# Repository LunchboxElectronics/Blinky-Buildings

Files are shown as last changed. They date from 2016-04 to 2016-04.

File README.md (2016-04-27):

# Blinky-Buildings
Blinky Buildings v1
- About:  
Blinky Buildings is a simple kit to teach people how to make derivatives of open source hardware. You are welcome to create a derivative of this kit as long as it abides by the open source hardware definition. 

This kit blinks 20 LEDs from an ATtiny85. The code was written in Arduino and uses a technique called Charlieplexing to drive multiple LEDs using just 5 pins of the ATtiny.

This kit assumes you know how to solder. If not, there are plenty of online tutorials on how to solder. The kit is fairly quick to put together, roughly 10 minutes, and the chip has been programmed for you! 

- Materials and tools:
Here are the parts you’ll need to get stared:
20 LEDs (with a max current of 20mA)
5 Resistors (for 3.2v forward voltage LEDs, I used 680 Ohm resistors)
1 ATtiny85
1 battery holder
1 3v battery
1 switch

Here are the tools you’ll need to get stared:
Soldering Iron
Solder
wire clippers

More information and documentation, including an assembly guide, lives here: bit.ly/blinkybuildings

- Attribution: 
The code for this project was downloaded from http://code.google.com/p/avr-hardware-random-number-generation/ Original code by Geoff  Steele, altered by commenting some code out to blink LEDs on and off by Alicia Gibb.
The original Fritzing design of charlieplexing 20 LEDs was downloaded from http://fritzing.org/projects/charlieplex-snowfallshooting-star-20-leds by Davy Uittenbogerd. Alicia Gibb drew this schematic in Eagle and altered in into the Empire State Blinky Building form factor.
The original code and the hardware files are both under a CC-BY-SA creative commons license.
Code: CC-BY-SA: Geoff Steele
Fritzing layout: CC-BY-SA: Davy Uittenbogerd
Blinky Building schematic, board file and BOM: CC-BY-SA: Alicia Gibb

- Licensing: 
Blinky Buildings is an open source hardware product and follows the open source hardware definition: www.oshwa.org/definition
The license on the source files for Blinky Buildings is CC-BY-SA

Distributed as-is; no warranty given. Not suitable for people who might eat electronics.

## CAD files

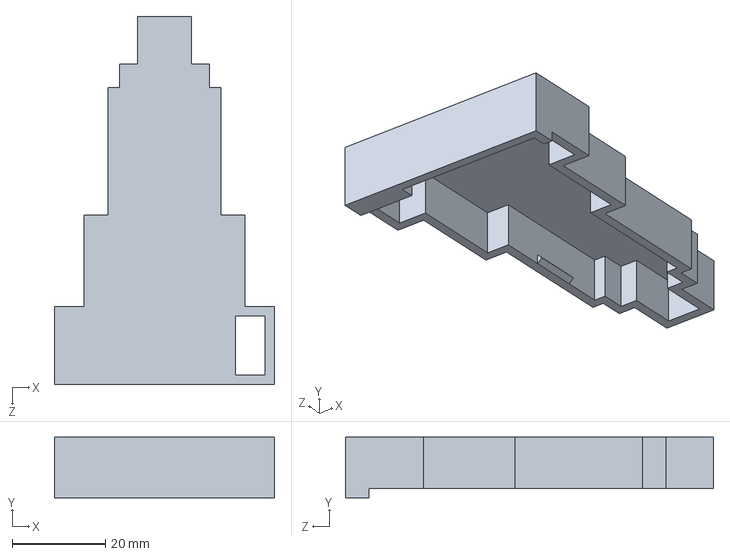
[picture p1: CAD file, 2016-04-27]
FinalBlinkyBuildingsCase.SLDPRT
47.2 x 13.0 x 78.9 mm

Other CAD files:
FinalBlinkyBuildingsCase.STL

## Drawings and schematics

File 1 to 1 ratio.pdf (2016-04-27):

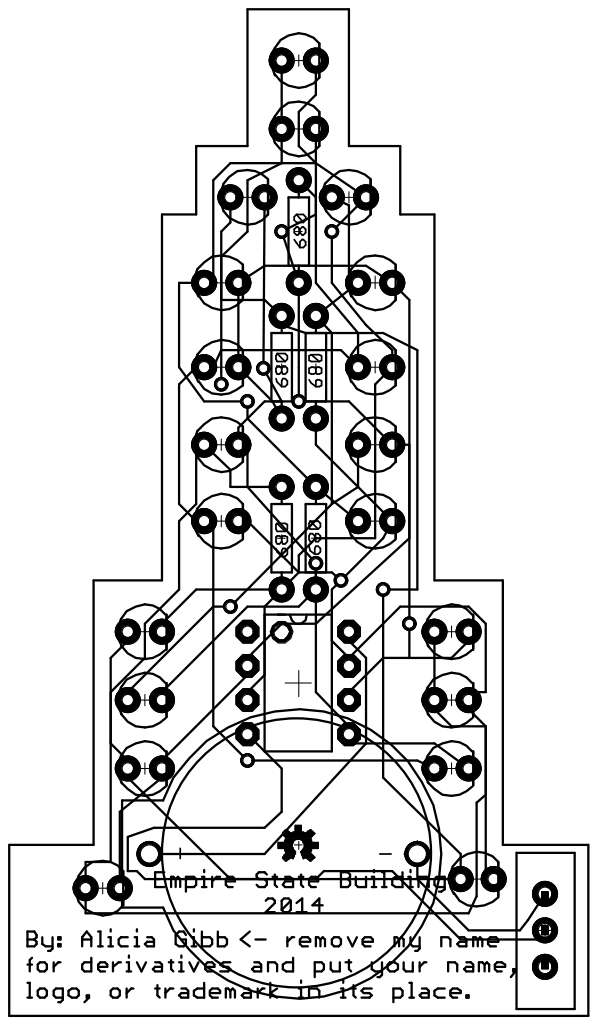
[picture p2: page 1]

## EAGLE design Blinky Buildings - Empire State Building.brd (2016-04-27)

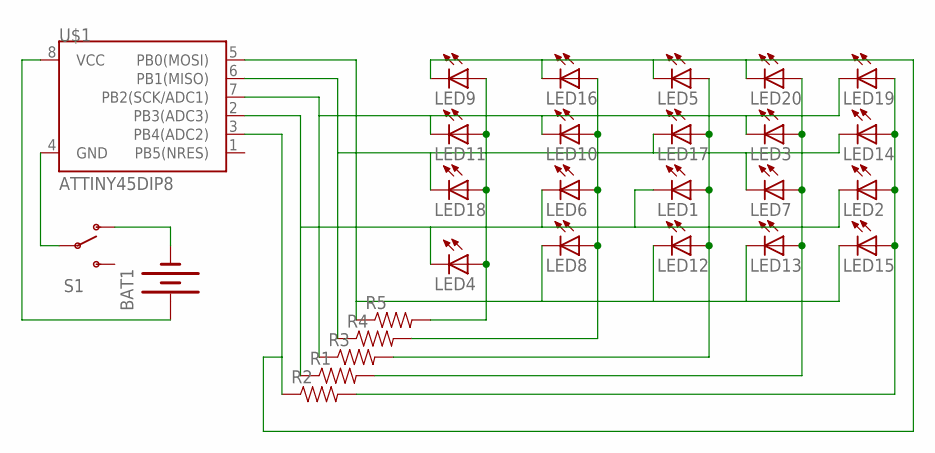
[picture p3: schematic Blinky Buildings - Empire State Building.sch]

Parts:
BAT1: BATTERY20PTH; BATTCOM_20MM_PTH
LED1, LED2, LED3, LED4, LED5, LED6, LED7, LED8, LED9, LED10, LED11, LED12, LED13, LED14, LED15, LED16, LED17, LED18, LED19, LED20: LED3MM
R1, R2, R3, R4, R5: RESISTORAXIAL-0.3; AXIAL-0.3
S1: SWITCH-SPSTKIT; SWITCH-SPDT_KIT
U$1: ATTINY45DIP8; DIP08

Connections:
unnamed: LED5.K (C), LED9.K (C), LED16.K (C), LED20.K (C), R2.P$1 (1), U$1.3 (PB4(ADC2))
unnamed: LED1.K (C), LED2.K (C), LED4.K (C), LED6.K (C), R1.P$1 (1), U$1.2 (PB3(ADC3))
unnamed: LED3.K (C), LED10.K (C), LED11.K (C), LED19.K (C), R3.P$1 (1), U$1.7 (PB2(SCK/ADC1))
unnamed: LED7.K (C), LED14.K (C), LED17.K (C), LED18.K (C), R4.P$1 (1), U$1.6 (PB1(MISO))
unnamed: LED8.K (C), LED12.K (C), LED13.K (C), LED15.K (C), R5.P$1 (1), U$1.5 (PB0(MOSI))
unnamed: LED3.A, LED7.A, LED13.A, LED20.A, R1.P$2 (2)
unnamed: LED4.A, LED9.A, LED11.A, LED18.A, R5.P$2 (2)
unnamed: LED6.A, LED8.A, LED10.A, LED16.A, R4.P$2 (2)
unnamed: LED1.A, LED5.A, LED12.A, LED17.A, R3.P$2 (2)
unnamed: LED2.A, LED14.A, LED15.A, LED19.A, R2.P$2 (2)
unnamed: S1.2, U$1.4 (GND)
unnamed: BAT1.1 (+), U$1.8 (VCC)
unnamed: BAT1.2 (-), S1.1 (O)

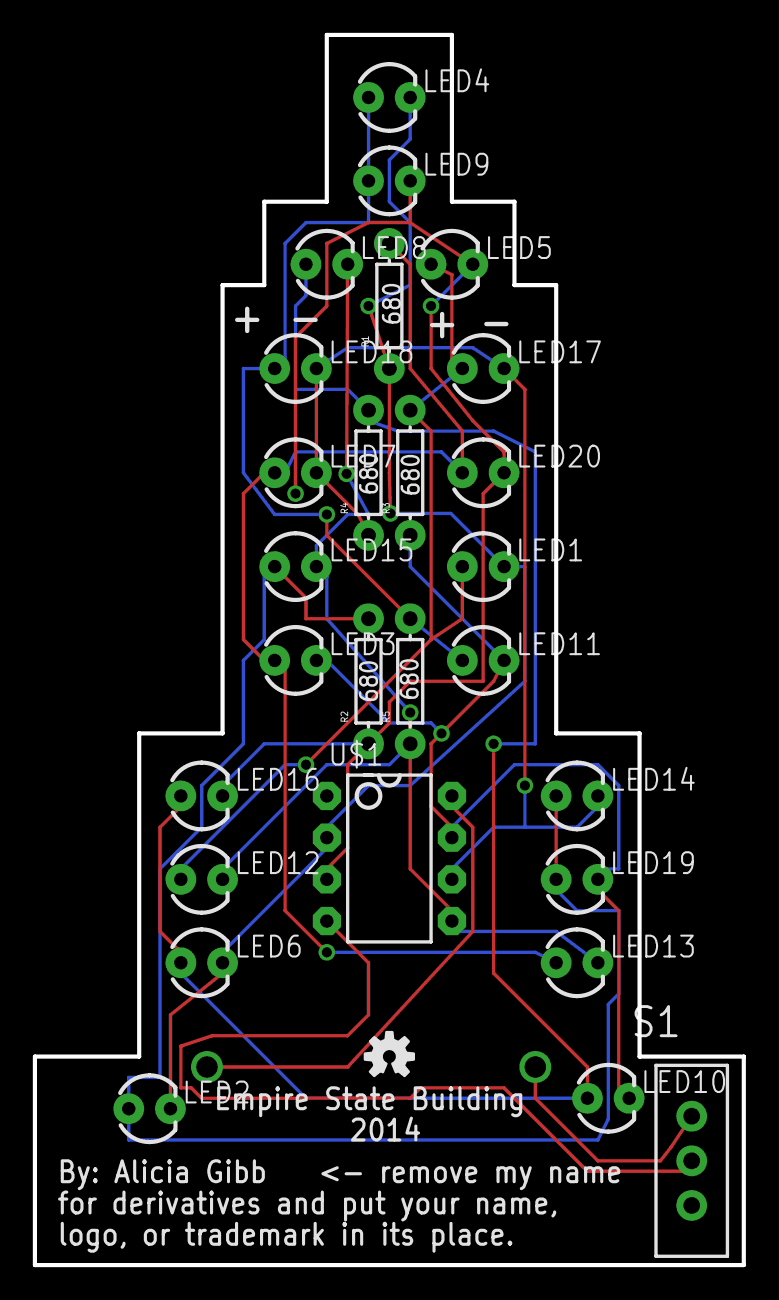
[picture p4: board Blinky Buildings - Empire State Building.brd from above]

Board: 2 copper layers, 43.2 x 74.9 mm, 29 parts (1 on the bottom side), 13 nets.

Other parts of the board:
U$2: OSHW-LOGO-S

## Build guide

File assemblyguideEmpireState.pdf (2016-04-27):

## Blinking Buildings Empire State Assembly Guide

Blinky Buildings kit contains:
20 LEDs
5 680 Ohm Resistors
1 ATtiny85

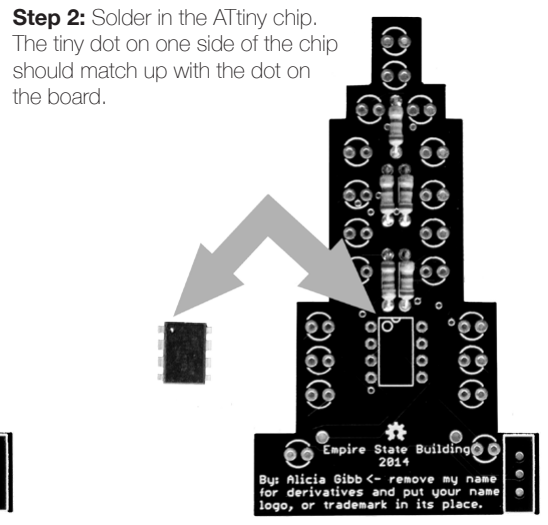
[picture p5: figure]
Step 2: Solder in the ATtiny chip. The tiny dot on one side of the chip should match up with the dot on the board.

## Assembly:

Tools you will need:
Soldering Iron
Solder
Wire clippers

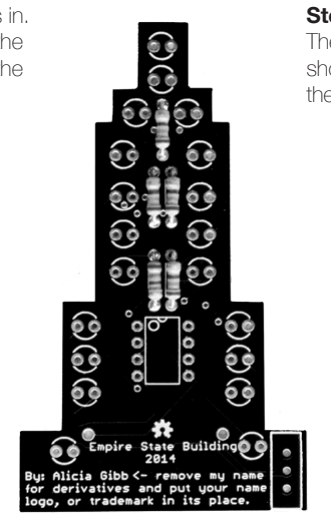
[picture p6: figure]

Step 1: Solder the 5 resistors in. Direction doesn't matter with the resistors. After soldering, cut the OHDGVR

1 Battery Holder
1 3v Battery
1 Switch

## LBE

Lunchbox Electronics

Step 5: On the back side of the board, solder in the battery holder. Insert the battery with the + face up.

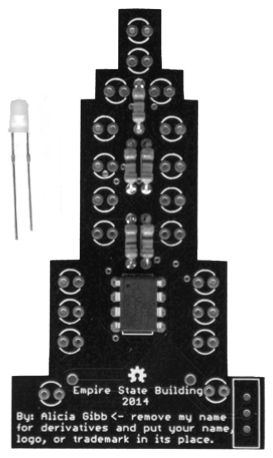
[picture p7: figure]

Step 6: <RX

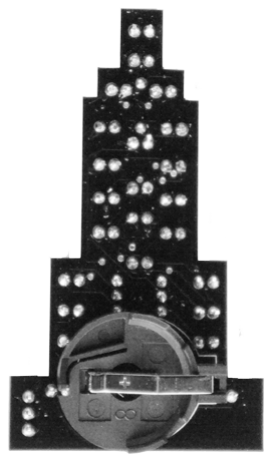
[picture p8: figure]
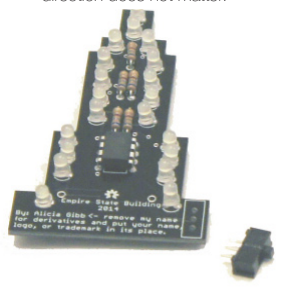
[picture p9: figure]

UH'RQH3RSWKHEDWWHU\LQDQGLSWKHVZLWFKRQ<D\%OLQNLQHVV

Step 4: Solder in the switch, direction does not matter.
Step 3: Take note of the direction of the LEDs. The long lead of the LED goes on the left side if your board is face up. &XWWKHOHDGRRQFHVROGHUHG6ROGHUDOO 20 LEDs in this direction.

Alicia Gibb
6RXUFHOHVELWO\EOLQN\EXLOGLQJV

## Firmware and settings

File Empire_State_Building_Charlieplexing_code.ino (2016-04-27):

#include <Entropy.h>
/* Original code downloaded fromhttps://github.com/strykeroz/ATTiny85-20-LED-snowflakes
Original code by Geoff  Steele. Alicia Gibb altered the code by commenting out the fade functions so the building blinks 
LEDs on and off rather than fade LEDs on and off. 
The original code is still all there if others wanted to keep playing with it, just put the duty cycle back in, 
which have a fade effect rather than a blink effect.
The delays have also been changed, but can easily be reinstated by looking at the original code.

____ _ _ _ _ ____ ___
/ ___| |__ __ _ _ __| (_) ___ _ __ | | _____ _|___ \ / _ \ ___ _ __ _____ __
| | | '_ \ / _` | '__| | |/ _ \ '_ \| |/ _ \ \/ / __) | | | / __| '_ \ / _ \ \ /\ / /
| |___| | | | (_| | | | | | __/ |_) | | __/> < / __/| |_| \__ \ | | | (_) \ V V /
\____|_| |_|\__,_|_| |_|_|\___| .__/|_|\___/_/\_\_____|\___/|___/_| |_|\___/ \_/\_/
|_|
Charlieplexing 20 LEDs using 5 ATTiny85 pins with fading by
varying the duty cycle of each LED in the 'tail'.
ATTiny85 connections
Leg Function
1 Reset, no connection
2 D3 GREEN
3 D4 ORANGE
4 GND
5 D0 WHITE
6 D1 BLUE
7 D2 YELLOW
8 +5V
Tested on ATTiny85 running at 8MHz.
*/


//// each block of 4 LEDs in the array is groupled by a common anode (+, long leg)
//// for simplicity of wiring on breadboard, using a colour code
#define GREEN 0
#define ORANGE 1
#define WHITE 2
#define BLUE 3
#define YELLOW 4

//// pin definitions {GREEN, ORANGE, WHITE, BLUE, YELLOW}
const int charliePin[5] = {
  3, 4, 0, 1, 2};

//// Charlieplexed LED definitions (current flowing from-to pairs)
const int LED[20][2] = {
  {
    ORANGE, GREEN }
  , //// 0 (GREEN GROUP)
  {
    WHITE, GREEN }
  , //// 1
  {
    BLUE, GREEN }
  , //// 2
  {
    YELLOW, GREEN }
  , //// 3
  {
    GREEN, ORANGE }
  , //// 4 (ORANGE GROUP)
  {
    WHITE, ORANGE }
  , //// 5
  {
    BLUE, ORANGE }
  , //// 6
  {
    YELLOW, ORANGE }
  , //// 7
  {
    GREEN, WHITE }
  , //// 8 (WHITE GROUP)
  {
    ORANGE, WHITE }
  , //// 9
  {
    BLUE, WHITE }
  , //// 10
  {
    YELLOW, WHITE }
  , //// 11
  {
    GREEN, BLUE }
  , //// 12 (BLUE GROUP)
  {
    ORANGE, BLUE }
  , //// 13
  {
    WHITE, BLUE }
  , //// 14
  {
    YELLOW, BLUE }
  , //// 15
  {
    GREEN, YELLOW }
  , //// 16 (YELLOW GROUP)
  {
    ORANGE, YELLOW }
  , //// 17
  {
    WHITE, YELLOW }
  , //// 18
  {
    BLUE, YELLOW } //// 19
};

//// other
int current = 0; //// LED in array with current focus
int previous = 0; //// previous LED that was lit

void setup() {
  Entropy.Initialize();
  randomSeed(Entropy.random());
}

void loop() {
  unsigned long loopCount = 0; //// used to determine duty cycle of each LED
  unsigned long timeNow = millis(); //
  unsigned long displayTime = 10 + random(10); //// milliseconds to spend at each focus LED in descent
  while(millis()- timeNow < (displayTime+current)) { //// animation slows toward end
    loopCount++;
    //// the "snowflake" gets full duty cycle. When it gets to the end, hold it at the end until the tail collapses
    if (current > 19) charlieOFF(19); //This is altered from the original code, to turn LEDs off once the blink is over
    else charlieON(current);
    //// each member of tail has reduced duty cycle, and never get to the final position
    if(!(loopCount % 3)) if(current-1 >=0 && current-1 < 19) charlieOFF(current-1);
    if(!(loopCount % 6)) if(current-2 >=0 && current-2 < 19) charlieOFF(current-2);
    if(!(loopCount % 9)) if(current-3 >=0 && current-3 < 19) charlieOFF(current-3);
    if(!(loopCount % 12)) if(current-4 >=0 && current-4 < 19) charlieOFF(current-4);
  }

  current++;
  if(current==23) { //// start over 
    //Alicia commented out the below code to make the LEDs blink on and off rather than fade out.
    //// now fade out the snowflake in that final position #19
   for(int dutyCycle = 3; dutyCycle <= 15; dutyCycle += 3) {
      //loopCount = 0;
      //timeNow = millis();
      //while(millis() - timeNow < (displayTime+current*2)) { // fade out as slow as animation has achieved by now
      //  loopCount++;
       if(!(loopCount % dutyCycle)) charlieON(19);
      else charlieOFF(19);
     // } 
    } 
    current = 0;
    charlieOFF(19); //// turn off the remaining (possibly) lit LED
    delay(50); 
    //+ random(3000)); //// and then rinse, repeat...after a short pause
  }
}

//// --------------------------------------------------------------------------------
//// turns on LED #thisLED. Turns off all LEDs if the value passed is out of range
////
void charlieON(int thisLED) {
  //// turn off previous (reduces overhead, only switch 2 pins rather than 5)
  digitalWrite(charliePin[LED[previous][1]], LOW); // ensure internal pull-ups aren't engaged on INPUT mode
  pinMode(charliePin[LED[previous][0]], INPUT);
  pinMode(charliePin[LED[previous][1]], INPUT);

  //// turn on the one that's in focus
  if(thisLED >= 0 && thisLED <= 19) {
    pinMode(charliePin[LED[thisLED][0]], OUTPUT);
    pinMode(charliePin[LED[thisLED][1]], OUTPUT);
    digitalWrite(charliePin[LED[thisLED][0]], LOW);
    digitalWrite(charliePin[LED[thisLED][1]], HIGH);
  }
  previous = thisLED;
}

//// --------------------------------------------------------------------------------
//// turns off LED #thisLED.
////
void charlieOFF(int thisLED) {
  digitalWrite(charliePin[LED[thisLED][1]], LOW); //// ensure internal pull-ups aren't engaged on INPUT mode
  pinMode(charliePin[LED[thisLED][0]], INPUT);
  pinMode(charliePin[LED[thisLED][1]], INPUT);
}

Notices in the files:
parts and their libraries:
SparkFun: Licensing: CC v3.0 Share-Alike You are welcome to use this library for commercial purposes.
